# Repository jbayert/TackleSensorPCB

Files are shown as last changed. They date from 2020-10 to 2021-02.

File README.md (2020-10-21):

# TackleSensorPCB
 Robotic Football Tackle Sensor Hardware Design created by Jon Bayert

 This is currenly under development. A very rough price will be $15-20 but depends on the number ordered. It will be sent out for assembly but will still need to be flashed.

 The current prototype design in the kicad repo looks like:

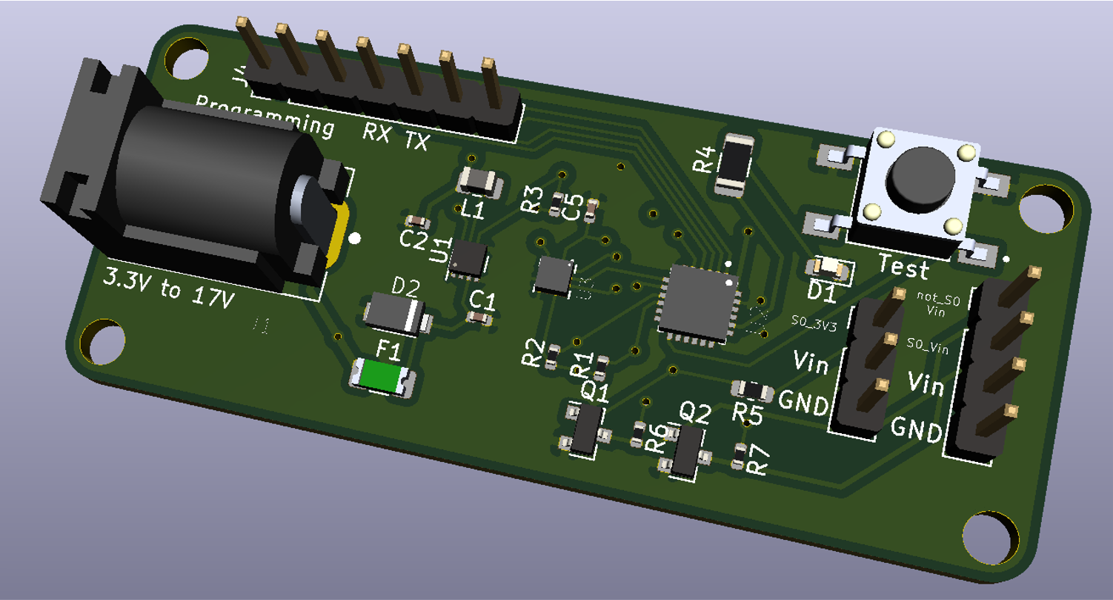
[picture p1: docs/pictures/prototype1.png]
The prototype
 

Also take a look at:

 * [The Typical Use](./docs/TypicalUse.md)
 * [The Schematic](./docs/Schematics/schematic.pdf)

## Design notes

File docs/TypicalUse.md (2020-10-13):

# Tackle Sensor Typical Use

## Pins

| Pin | Description |
|:---:|:---:|
| Vin | Input Voltage (3.3V to 17V) |
| GND | The ground pin |
| S0_3V3 | Tackle Signal at 3.3V (low is tackled) |
| S0_Vin | Tackle Signal at Vin Voltage (low is tackled) |
| not_S0_Vin | Inverted Tackle Signal at Vin Voltage (high is tackled) |

## 3.3V Signal to Microcontroller

The S0_3V3 pin will always output 3.3V regardless of Vin voltage. This can be useful to send a signal to a microcontroller such as ESP32 or a raspberry pi. 

Connect a Microcontroller to S0_3V3 pin

## 5V Signal to Microcontroller

The S0_Vin pin will always output the same voltage as Vin. This can be useful to send a signal to a microcontroller such as Arduinos with 5V pins.

Connect a Microcontroller to S0_Vin pin

## Drive LEDs with the Tackle Sensor

The S0_Vin pin can be connected as to LEDs. In this example the RED Led will be on when tackled and the green LED will be on when it is not tackled.  

Connect a Microcontroller to S0_Vin pin

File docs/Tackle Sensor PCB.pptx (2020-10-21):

## Tackle Sensor PCB

Jon Bayert
Oc-20-2020
https://github.com/jbayert/TackleSensorPCB

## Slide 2

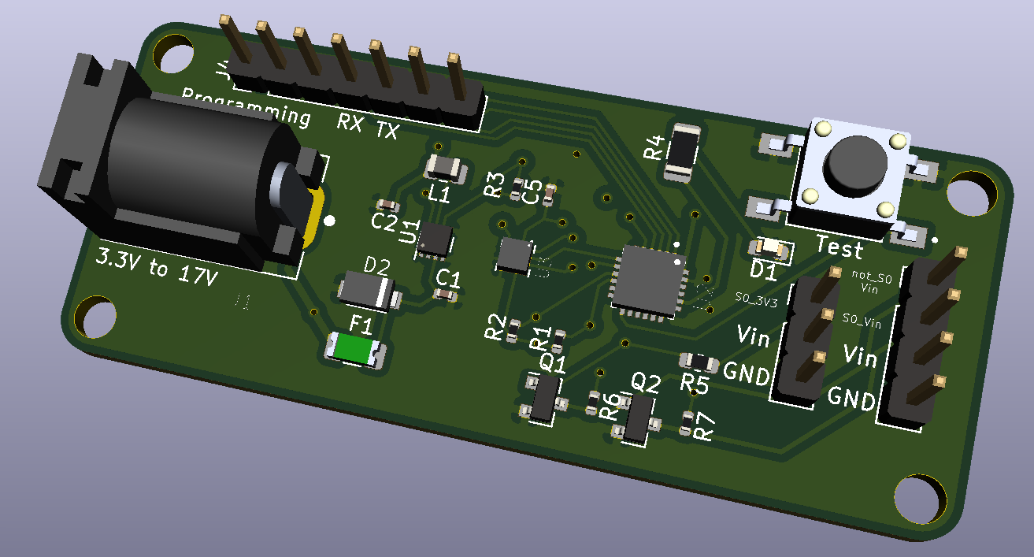
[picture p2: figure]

## Typical use

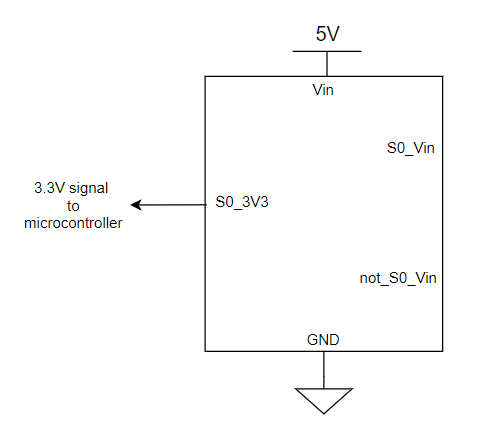
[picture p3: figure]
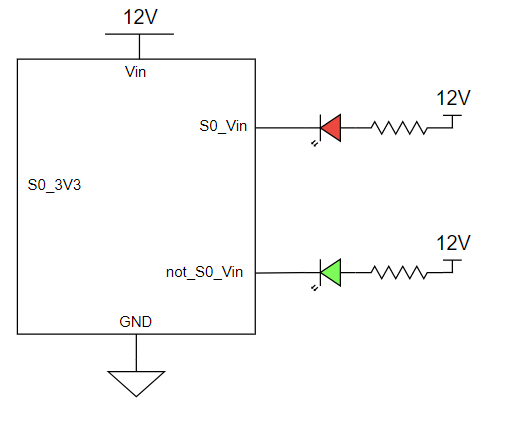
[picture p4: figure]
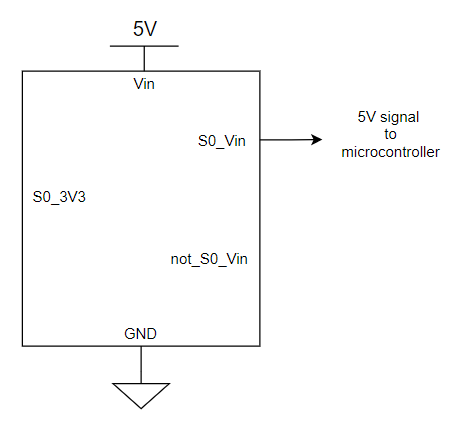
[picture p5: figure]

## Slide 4

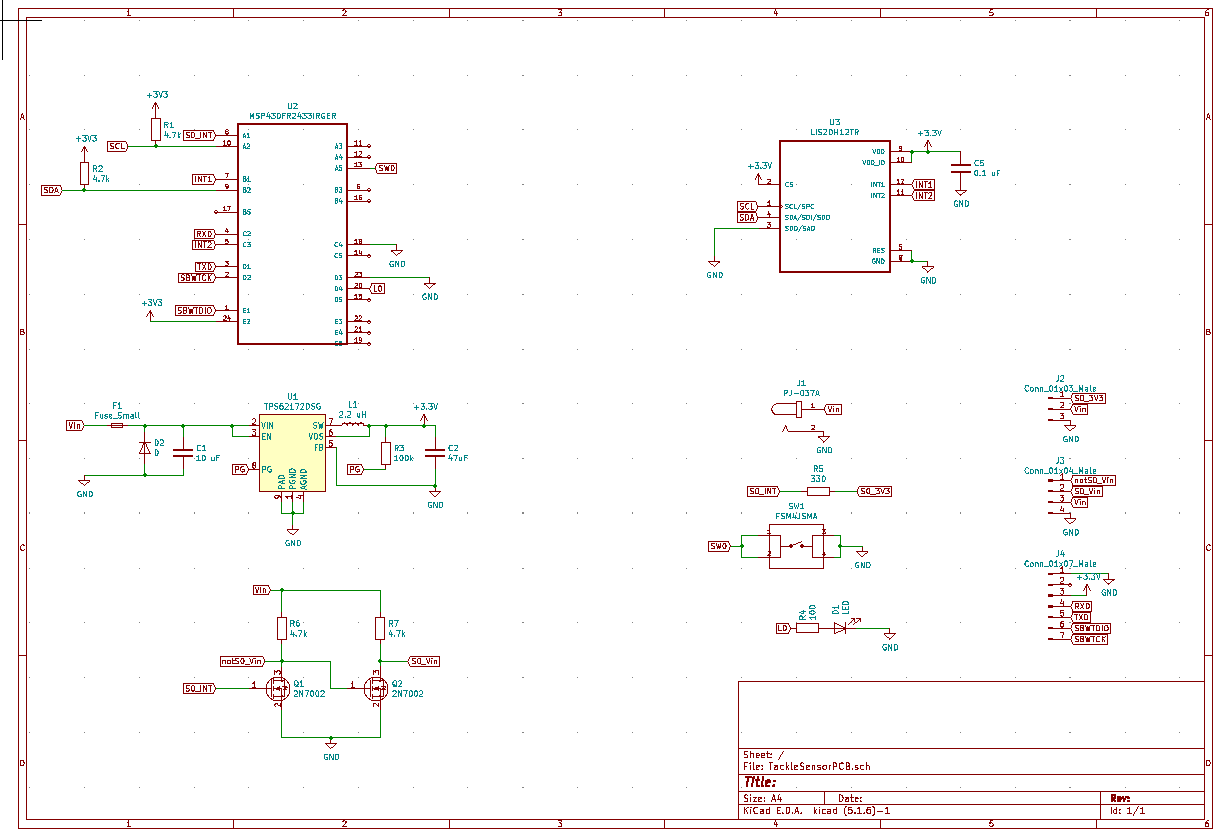
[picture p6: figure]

## Assembly

- Send out for SMD assembly. We just must flash it.
- Should cost $15-20. Bulk (50+ish) could bring that down

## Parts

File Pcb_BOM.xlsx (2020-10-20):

Item # | *Designator | *Qty | Manufacturer | *Mfg Part # | Description / Value | *Package/Footprint | Type | Your Instructions / Notes
1 |  | 4 |  |  | 4.7K 0402 5% | 0402 | SMD
2 |  | 1 |  |  | 330ohms 603 1% | 603 | SMD
3 |  | 1 |  |  | 100ohms 1206 5% | 1206 | SMD
4 |  | 1 |  |  | 100kohms 402 1% | 402 | SMD
5 |  | 4 |  |  | 10uF 20V 0402 |  | SMD
6 |  | 1 |  |  | 100NF 6V 0402 |  | SMD
7 |  |  |  | PTS636 SM25F SMTR LFS | Tactile Switch |  | SMD
8 |  |  |  |  |  |  | SMD
9 |  |  |  |  |  |  | SMD
10 |  |  |  |  |  |  | SMD
11 |  |  |  |  |  |  | SMD
12 |  |  |  |  |  |  | SMD
13 |  |  |  |  |  |  | SMD
14 |  |  |  |  |  |  | SMD
15 |  |  |  |  |  |  | SMD

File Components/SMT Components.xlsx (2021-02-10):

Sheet: Sheet1
 | Part | Name | Quantity | Cost | Total | Extened Part on JLC PCB | Package | similar digikey
 | MSP430FR2433 |  | 1 | 0.9566 | 0.9566 | Extended
 | LIS3DH |  | 1
 | TPS62172DSGR |  | 1 | 0.5735 | 0.5735 | Extended
X | 0402WGF4701TCE | 4.7K 0402 5% | 4 | 0.0011 | 0.0044 |  | 402
X | CL05B104KO5NNNC | 100NF 16V 0402 | 1 | 0.003 | 0.003 |  | 402
X | 0603WAF3300T5E | 330ohms 603 1% | 1 | 0.0019 | 0.0019 |  | 603
X | 1206W4F1000T5E | 100ohms 1206 5% | 1 | 0.0058 | 0.0058 |  | 1206
X | 0402WGF1003TCE | 100kohms 402 1% | 1 | 0.006 | 0.006 |  | 402
 | TS-1187A-B-A-B | switch | 1 | 0.0213 | 0.0213 | Extended
 | nSMD020 | fuse | 1 | 0.0488 | 0.0488 | Extended | 1206
 | SM4007PL | diode | 1 | 0.0089 | 0.0089 |  | SOD-123FL
X | CL21A106KAYNNNE | 10uF 20V 0402 | 4 | 0.0122 | 0.0488 |  | 402
 | 2N7002 | mosfet | 2 | 0.0209 | 0.0418 |  | SOT-23-3
 | KT-0603R | LED | 1 | 0.0079 | 0.0079 |  | LED_0603
 | CMI201209U2R2KT | 2.2uH | 1 | 0.0089 | 0.0089 |  | 805
 |  | Count | 22 | Total | 1.7376

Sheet: pcbway
 | 20 | 100
Board | 1.8 | 1.7
Assembly | 6.4 | 2.8
Shiping | 1 | 0.72
Components | 1.7376 | 1.7376
Sum | 10.9376 | 6.9576

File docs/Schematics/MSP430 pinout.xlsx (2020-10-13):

 |  | MSP430
E1 | 1 | !RST/NMI/SBWTDIO | SBWTDIO |  |  | Pin on MSP430 | Interrupt pirority
D2 | 2 | TEST/SBWTCK | SBWTCK | Signal Out | Need timer | 8 (TA0.1)
D1 | 3 | P1.4/UCA0TXD/UCA0SIMO/TA1.2/TCK/A4/VREF+ | TXD | Button In |  | 13 (P2.3) | 3
C2 | 4 | P1.5/UCA0RXD/UCA0SOMI/TA1.1/TMS/A5 | RXD | LED OUT |  | 12 (P3.2)
C3 | 5 | P1.6/UCA0CLK/TA1CLK/TDI/TCLK/A6 | INT2
B3 | 6 | P1.7/UCA0STE/SMCLK/TDO/A7
B1 | 7 | P1.0/UCB0STE/TA0CLK/A0/Veref+ | INT1 | accelerometer
A1 | 8 | P1.1/UCB0CLK/TA0.1/A1 | S0 (Signal Out) |  | Pin on MMA | Pin on MSP430
B2 | 9 | P1.2/UCB0SIMO/UCB0SDA/TA0.2/A2/Veref | I2C SDA | GND
A2 | 10 | P1.3/UCB0SOMI/UCB0SCL/MCLK/A3 | I2C SCL | 3V3
A3 | 11 | P2.2/ACLK |  | SDA | 6 | 9
A4 | 12 | P3.0 |  | SCL | 4 | 10
A5 | 13 | P2.3 | B0 (Button In) | INT1 | 11 | P1.0 (7) | 1
C5 | 14 | P3.1/UCA1STE |  | INT2 | 9 | P1.6(5) | 2
D5 | 15 | P2.4/UCA1CLK |  | SA0 | 7 | GND
B4 | 16 | P2.5/UCA1RXD/UCA1SOMI
B5 | 17 | P2.6/UCA1TXD/UCA1SIMO
C4 | 18 | DVSS | GND
E5 | 19 | P2.7
D4 | 20 | P3.2 | L0 (LED OUT)
E4 | 21 | P2.0/XOUT
E3 | 22 | P2.1/XIN
D3 | 23 | DVSS | GND
E2 | 24 | DVCC | 3V3
 | 25 | PAD | GND

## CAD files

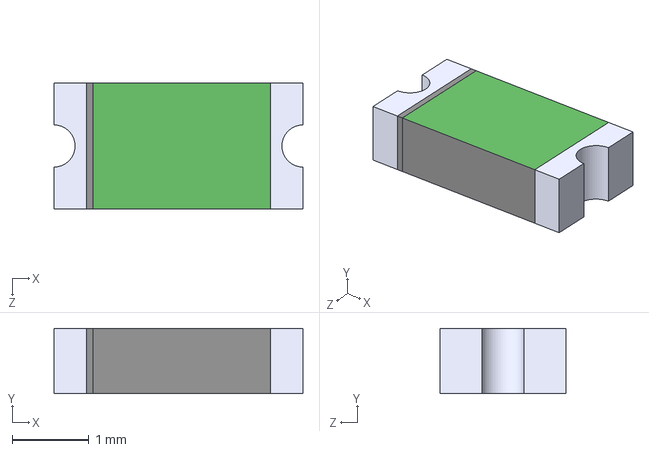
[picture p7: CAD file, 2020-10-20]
TackleSensorPCB/Components/0ZCJ0200FF2C.STEP
3.25 x 0.85 x 1.65 mm

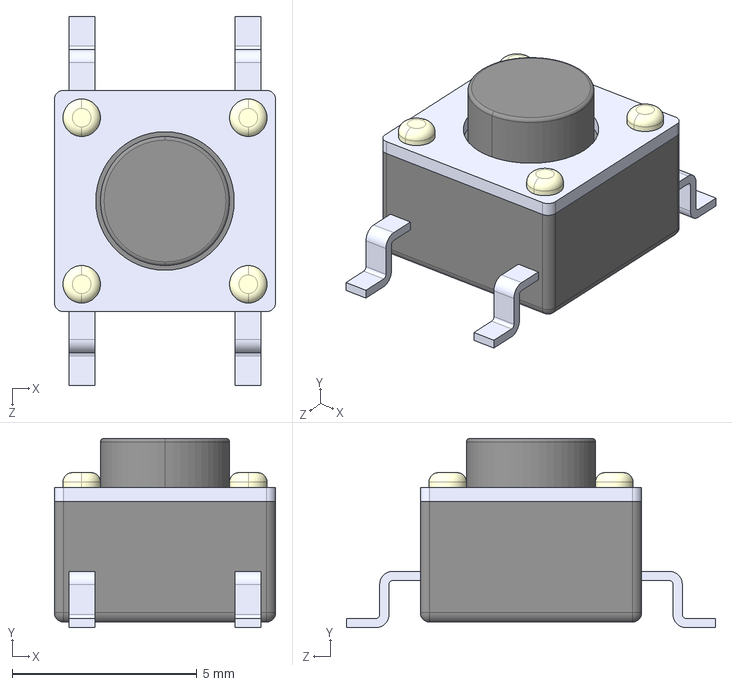
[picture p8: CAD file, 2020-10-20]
TackleSensorPCB/Components/FSM4JSMA/FSM4JSMA.STEP
6.00 x 5.13 x 10.0 mm

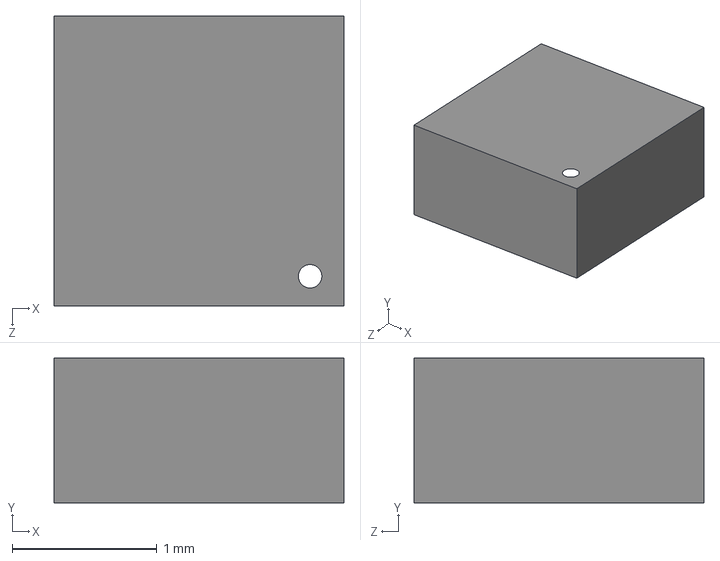
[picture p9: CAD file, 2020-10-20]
TackleSensorPCB/Components/LIS2DH12TR/LIS2DH12TR--3DModel-STEP-56544.STEP
2.00 x 1.00 x 2.00 mm

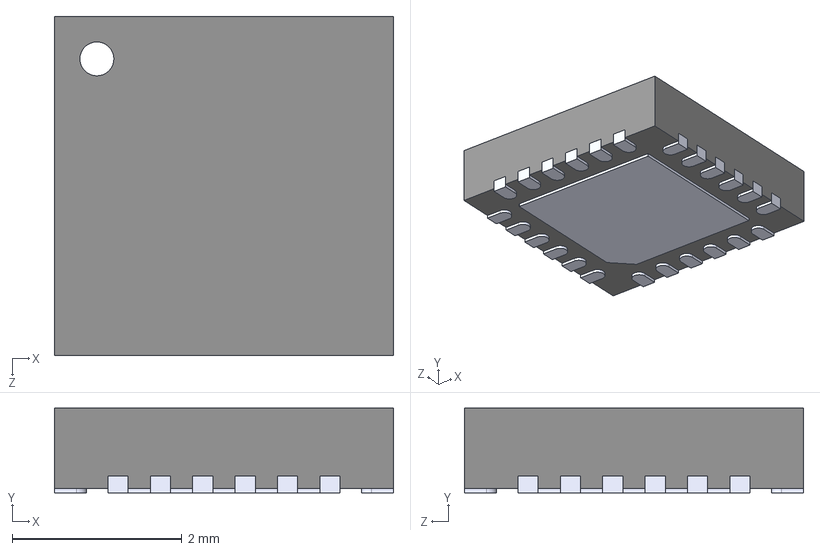
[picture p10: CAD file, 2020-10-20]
TackleSensorPCB/Components/MSP430FR2433IRGER/MSP430FR2433IRGER.STEP
4.00 x 1.00 x 4.00 mm

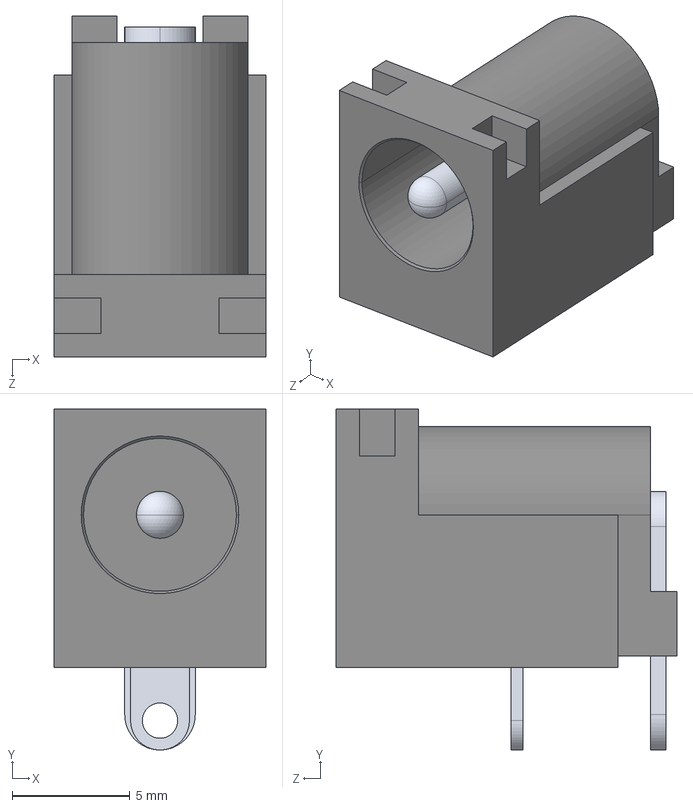
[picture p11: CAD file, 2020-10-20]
TackleSensorPCB/Components/PJ-037A/PJ-037A.STEP
9.00 x 14.5 x 14.5 mm

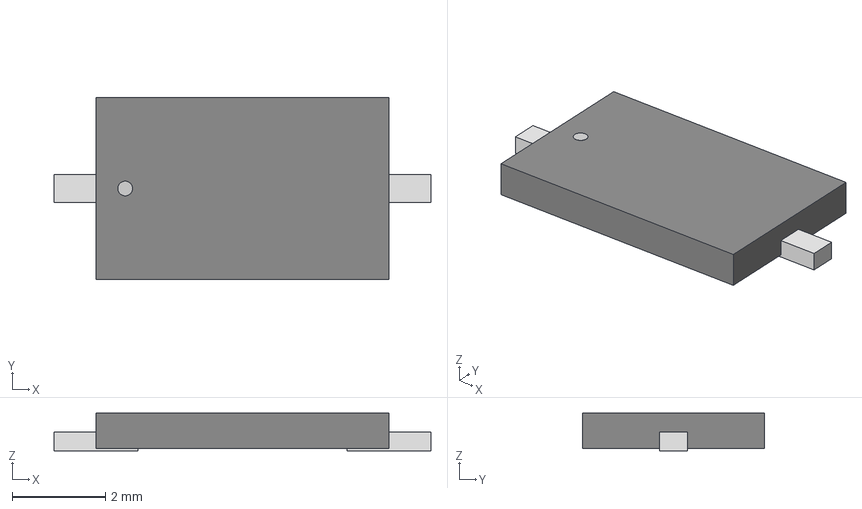
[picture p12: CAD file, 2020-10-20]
TackleSensorPCB/Components/PTS636_Tactile_Switch/STEP/SW2_PTS636SM25FSMTRLFS_CNK.step
8.10 x 3.91 x 0.815 mm

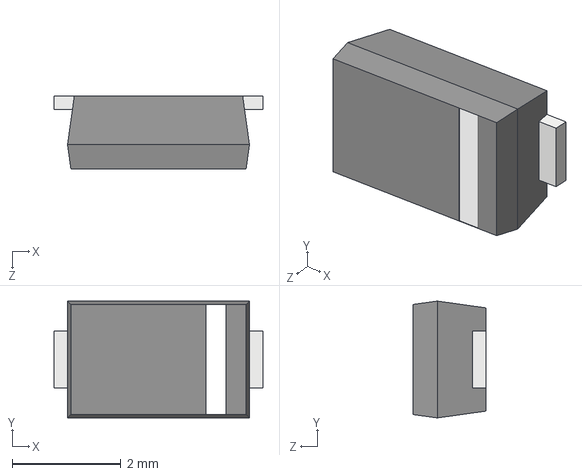
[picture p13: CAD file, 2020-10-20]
TackleSensorPCB/Components/SOD-123FL/SOD-123FL.STEP
3.85 x 2.15 x 1.35 mm

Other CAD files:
TackleSensorPCB/Components/PTS636_Tactile_Switch/STEP/SW2_PTS636SM25FSMTRLFS_CNK-M.step
TackleSensorPCB/Components/PTS636_Tactile_Switch/STEP/SW2_PTS636SM25FSMTRLFS_CNK-L.step

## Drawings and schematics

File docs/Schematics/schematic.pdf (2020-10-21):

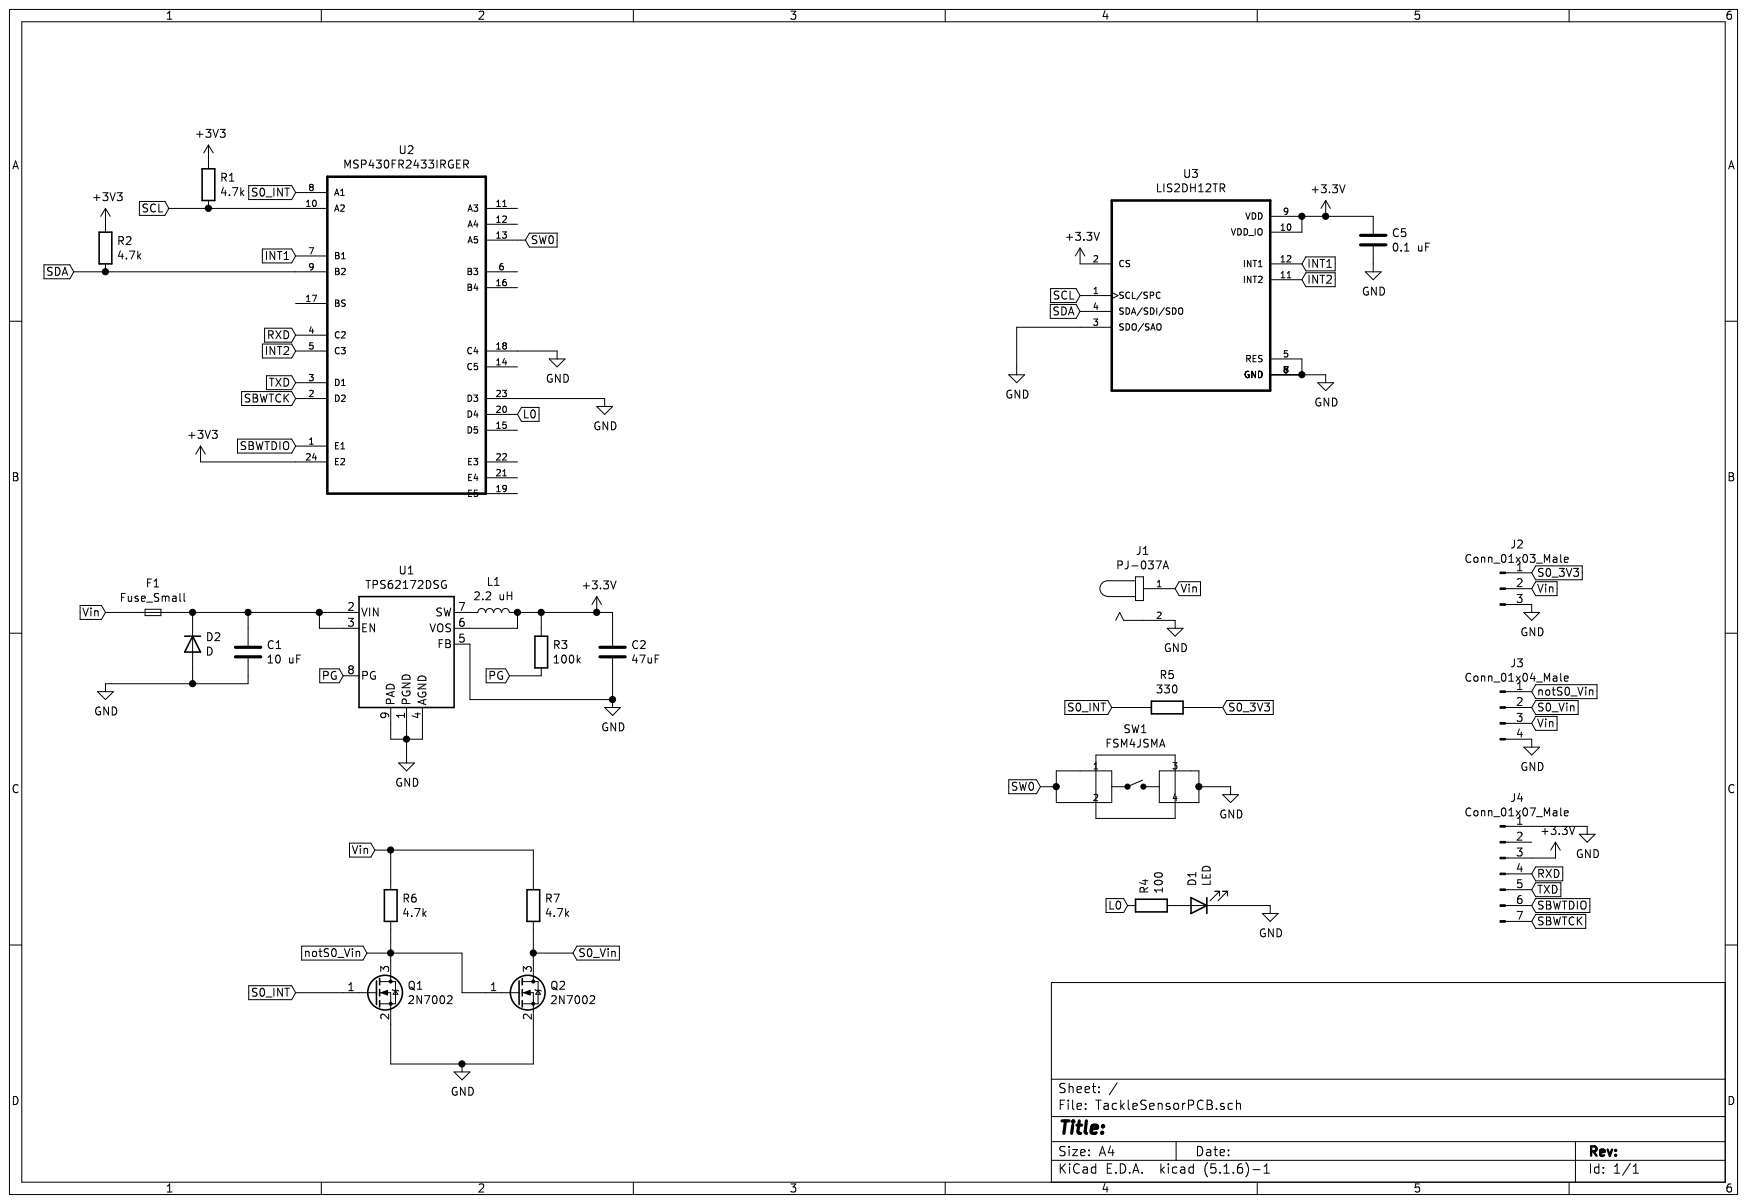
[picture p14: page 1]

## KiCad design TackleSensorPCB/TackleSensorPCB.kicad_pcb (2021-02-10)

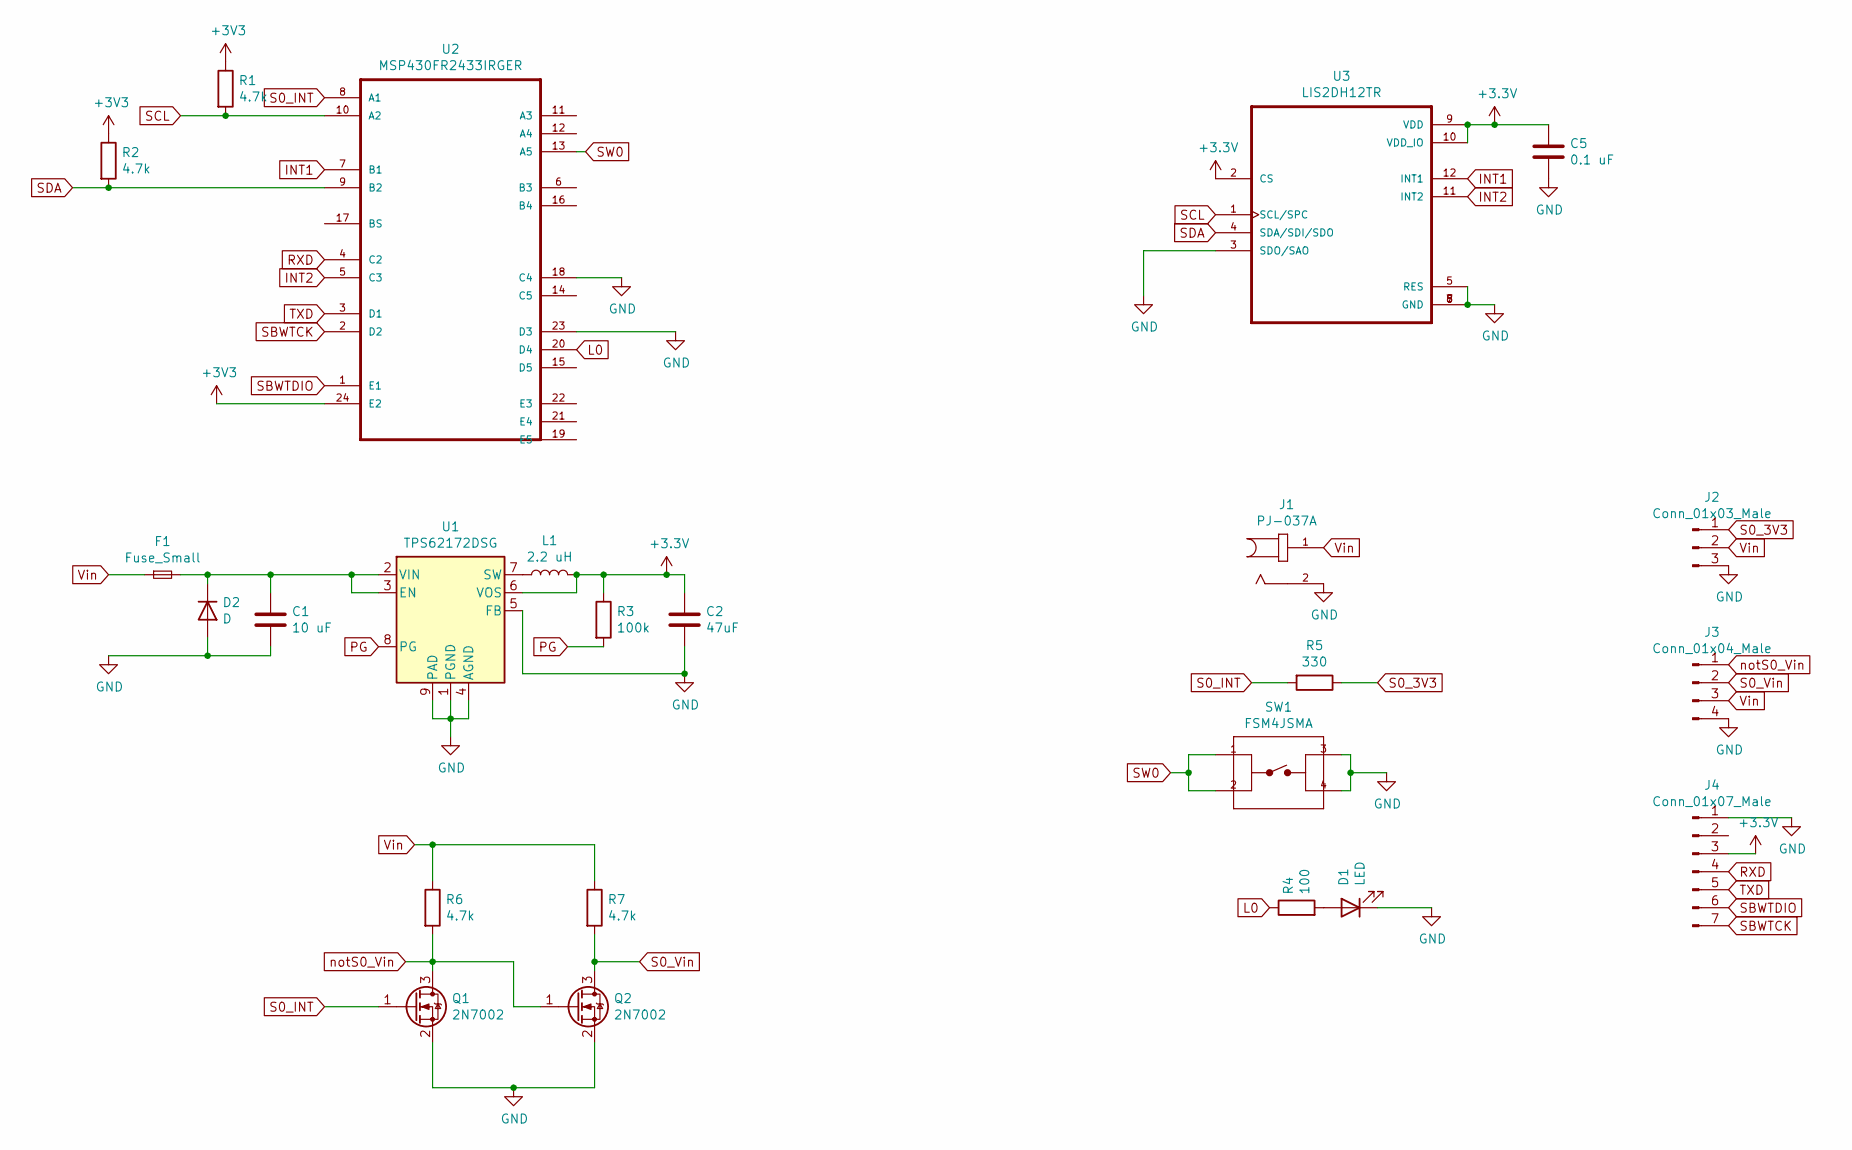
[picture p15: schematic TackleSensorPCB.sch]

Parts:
C1: 10 uF; C_0402_1005Metric
C2: 47uF; C_0402_1005Metric
C5: 0.1 uF; C_0402_1005Metric
D1: LED; LED_0603_1608Metric
D2: D; SOD123FL
F1: Fuse_Small; Fuse_1206_3216Metric
J1: PJ-037A; CUI_PJ-037A
J2: Conn_01x03_Male; PinHeader_1x03_P2.54mm_Vertical
J3: Conn_01x04_Male; PinHeader_1x04_P2.54mm_Vertical
J4: Conn_01x07_Male; PinHeader_1x07_P2.54mm_Vertical
L1: 2.2 uH; L_0805_2012Metric
Q1, Q2: 2N7002; SOT-23
R1, R2, R6, R7: 4.7k; R_0402_1005Metric
R3: 100k; R_0402_1005Metric
R4: 100; R_1206_3216Metric
R5: 330; R_0603_1608Metric
SW1: FSM4JSMA; TE_FSM4JSMA
U1: TPS62172DSG; WSON-8-1EP_2x2mm_P0.5mm_EP0.9x1.6mm_ThermalVias
U2: MSP430FR2433IRGER; QFN50P400X400X100-25N
U3: LIS2DH12TR; PQFN50P200X200100-12N

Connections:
GND: C1.2, C2.2, C5.2, D1.1 (K), D2.2 (A), J1.2, J2.3, J3.4, J4.1, Q1.2 (S), Q2.2 (S), SW1.3, SW1.4, U1.1 (PGND), U1.4 (AGND), U1.5 (FB), U1.9 (PAD), U2.18 (C4), U2.23 (D3), U2.25, U3.3 (SDO/SAO), U3.5 (RES), U3.6 (GND), U3.7 (GND), U3.8 (GND)
INT1: U2.7 (B1), U3.12 (INT1)
INT2: U2.5 (C3), U3.11 (INT2)
L0: R4.1, U2.20 (D4)
unnamed: C1.1, D2.1 (K), F1.2, U1.2 (VIN), U1.3 (EN)
unnamed: D1.2 (A), R4.2
unnamed: L1.1, U1.7 (SW)
PG: R3.2, U1.8 (PG)
RXD: J4.4, U2.4 (C2)
S0_3V3: J2.1, R5.1
S0_INT: Q1.1 (G), R5.2, U2.8 (A1)
S0_Vin: J3.2, Q2.3 (D), R7.2
SBWTCK: J4.7, U2.2 (D2)
SBWTDIO: J4.6, U2.1 (E1)
SCL: R1.2, U2.10 (A2), U3.1 (SCL/SPC)
SDA: R2.2, U2.9 (B2), U3.4 (SDA/SDI/SDO)
SW0: SW1.1, SW1.2, U2.13 (A5)
TXD: J4.5, U2.3 (D1)
Vin: F1.1, J1.1, J2.2, J3.3, R6.1, R7.1
notS0_Vin: J3.1, Q1.3 (D), Q2.1 (G), R6.2

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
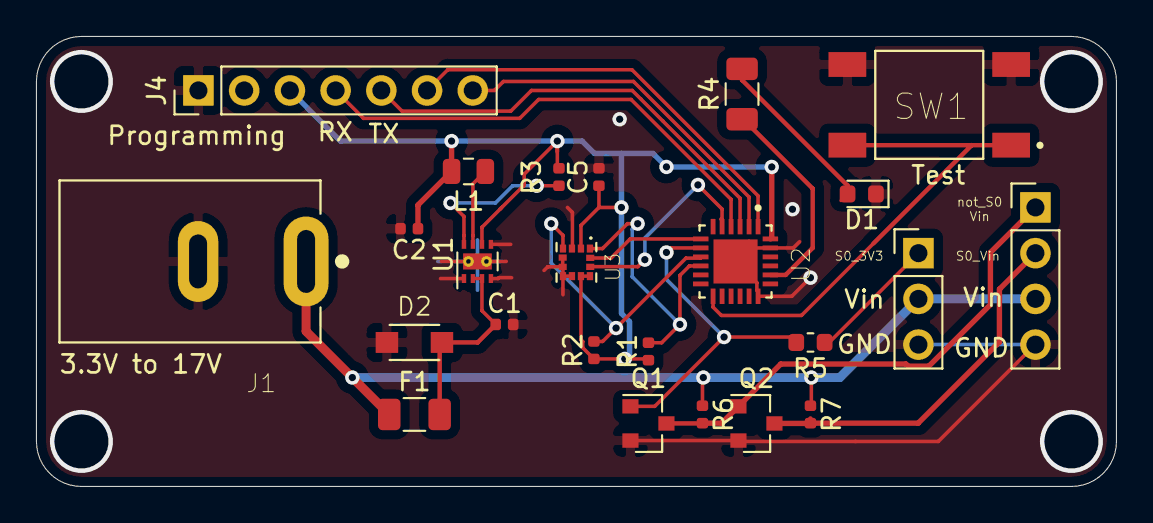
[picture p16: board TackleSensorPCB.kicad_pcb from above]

Board: 2 copper layers, 60.0 x 25.0 mm, 24 parts (0 on the bottom side), 21 nets.

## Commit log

2020-10-12 Added Fuse
    [TackleSensorPCB.sch]
2020-10-13 Added Documentation
    Fix the pull up resistors. They were on interrupts not i2c.
    Add not_S0_Vin pin.
    Add TypicalUse.md
    Add schematic.pdf
    Add SMT BOM
    Add pinout excel sheet
    [MSP430 pinout.xlsx, SMT Components.xlsx]
2020-10-14 Added Footprints
    [SMT Components.xlsx, TackleSensorPCB.sch]
2020-10-18 Created First Revision of PCB
    [TackleSensorPCB.sch]
2020-10-19 Updated to LS2
    [SMT Components.xlsx, TackleSensorPCB.kicad_pcb, TackleSensorPCB.sch]
2020-10-20 Completed 3D model
    [0ZCJ0200FF2C.STEP, FSM4JSMA.STEP, LIS2DH12TR--3DModel-STEP-56544.STEP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]
2020-10-20 Update Tackle Sensor PCB.pptx
2020-10-21 Updated the schematic
2021-02-10 Updated BOM
    [SMT Components.xlsx, TackleSensorPCB.kicad_pcb]
